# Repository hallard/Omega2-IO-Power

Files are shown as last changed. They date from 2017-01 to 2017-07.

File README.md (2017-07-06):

Power FTDI SPI and I2C or Full GPIO Shields for Onion Omega2
============================================================

These shields are used to power and to expose [Onion Omega2](https://onion.io/) gpio pins. it has just few minimal features such as wiring and 3V3 regulator and exists in 2 versions

- **Basic**: same size than Omega2, exposing Serial/SPI/I2C 
- **Full**: little bigger but exposing all Omega2 pins

Omega2 

**Features**   

- I2C Pullups placement
- I2C 4 pins connector
- SPI 6 pins connector
- Full Omega2 GPIO pins (Full version only)
- FTDI connector to Omega2 Serial0 (SMD or PTH) 
- USB Mini connector to power the whole thing and Omega2

You can find more information on Omega2 on their [site](https://onion.io/), it's really well [documented](https://docs.onion.io/omega2-docs/index.html) here.

**Waiting for V1.0 Boards from [PCBs.io](https://PCBs.io). I did not fully tested them yet, I will update ASAP. Use at your own risks**

Detailed Description
====================

Very simple, you plug your Omega2 on the shield, then you're ready to go. But pay attention, this board run at 3.3V.

You have 2 options to power board :

- Mini USB connector 5V goes to 3V3 regulator and you're ready to go
- Close JP1 and use **Only 3V3** FTDI connector that already have regulator on board. FTDI connector will then power the shield and Omega2 without any Mini USB plugged.

Take care if you are powered with mini USB and you want to use FTDI cable to connect to console, use a 3V3 FTDI cable and do not close JP1 connector

Here are example of FTDI 3V3 connector that should work 

- SparkFun Beefy 3 [FTDI Basic Breakout](https://www.sparkfun.com/products/13746) up to 600mA out at 3V3
- RocketScream [USB/Serial with CH340](http://www.rocketscream.com/blog/product/ch340g-usb-serial-adapter/) up to 100mA out at 3V3
- EZSBC [Usb To Serial UART 5V or 3V3](https://www.tindie.com/products/ddebeer/usb-to-serial--uart-5v-or-33v-695-/) up to 250mA out at 3V3
- WeMos [CH340G Breakout 5V 3.3V USB to serial](https://www.aliexpress.com/store/product/WEMOS-CH340G-Breakout-5V-3-3V-USB-to-serial-module/1331105_32664922086.html) up to 300mA out at 3V3

Schematics
==========

**Basic version** Click on image to zoom   
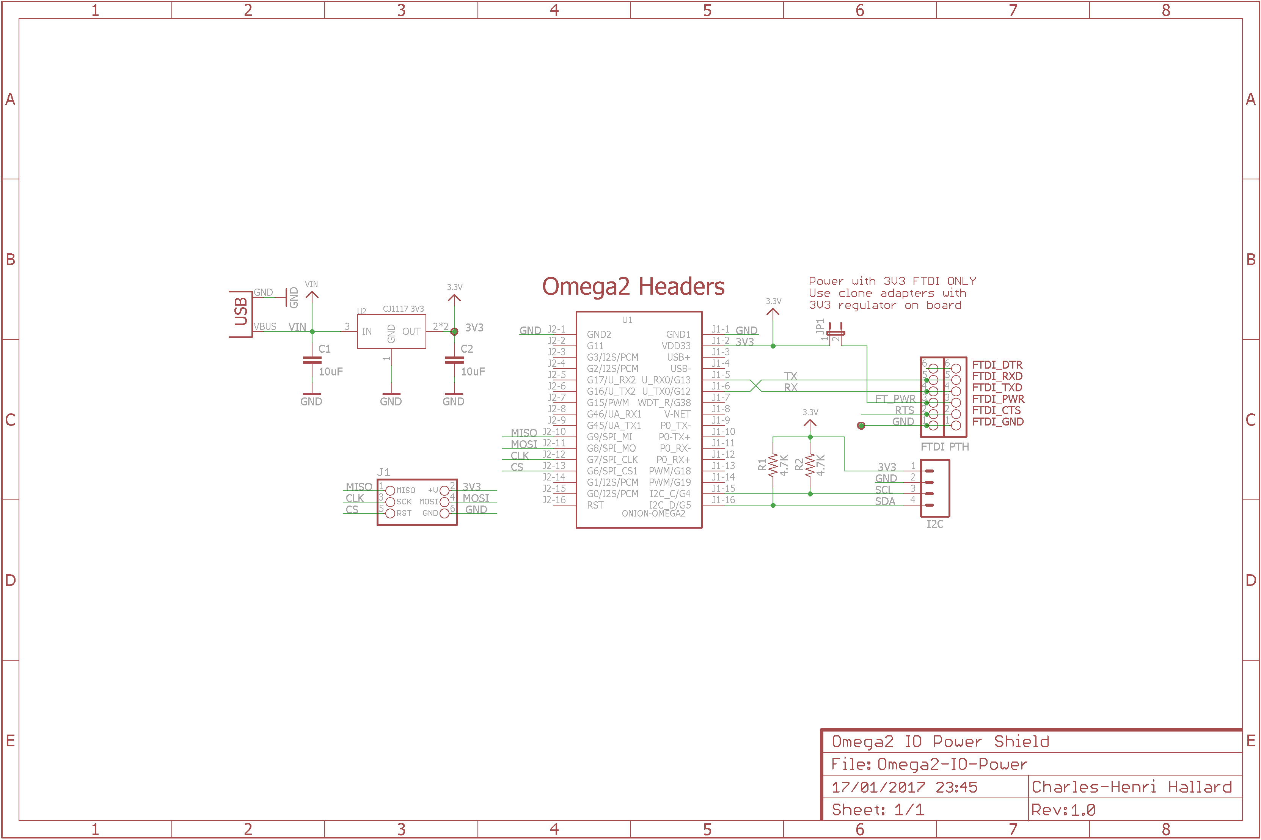
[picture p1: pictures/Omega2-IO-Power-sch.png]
  

**Full GPIO version** Click on image to zoom   
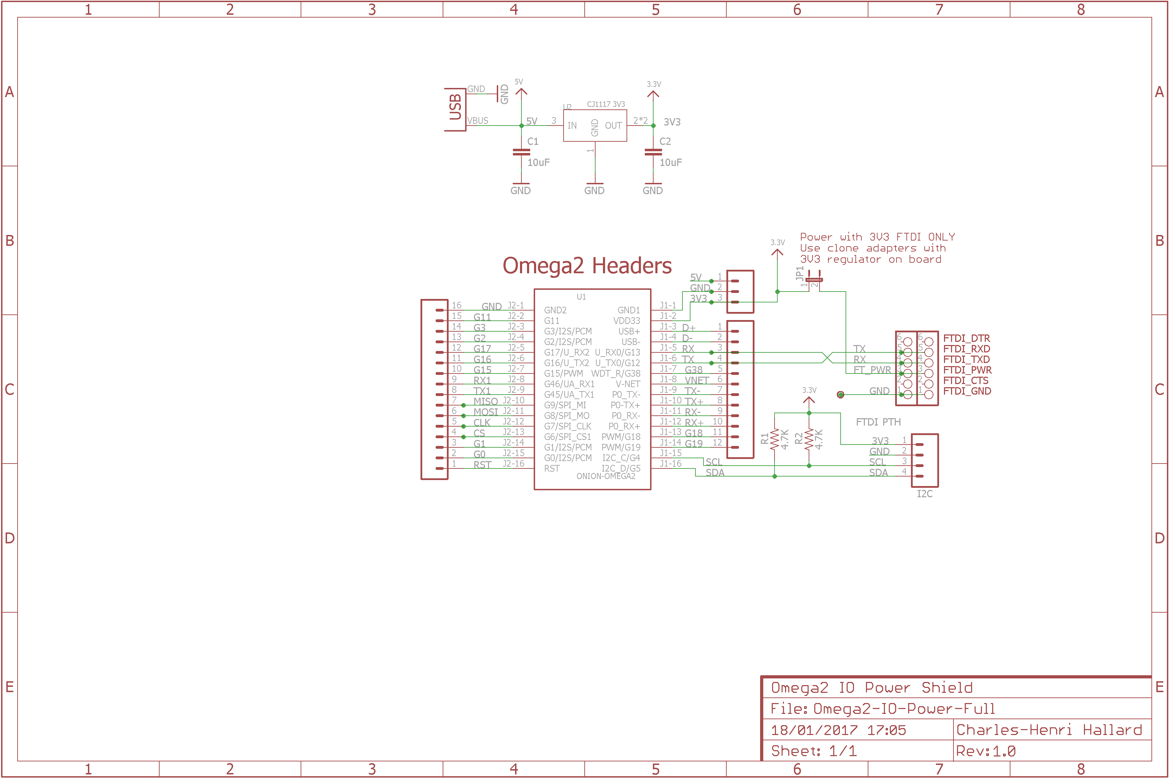
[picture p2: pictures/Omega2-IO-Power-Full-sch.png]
  

Boards
====== 

**Basic** Click on image to zoom   
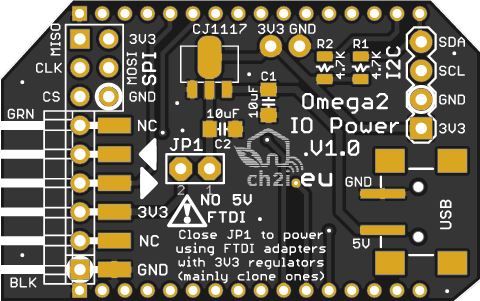
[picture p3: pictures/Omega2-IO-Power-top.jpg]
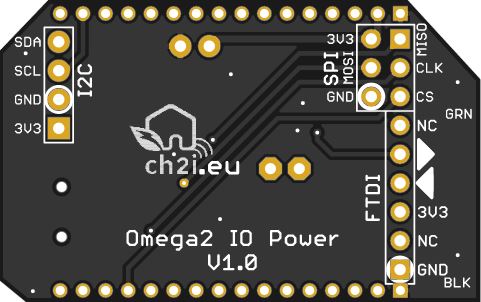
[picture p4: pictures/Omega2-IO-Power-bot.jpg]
&nbsp;&nbsp;&nbsp;

**Full GPIO version** Click on image to zoom   
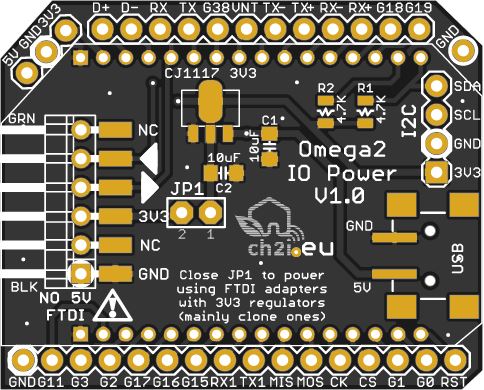
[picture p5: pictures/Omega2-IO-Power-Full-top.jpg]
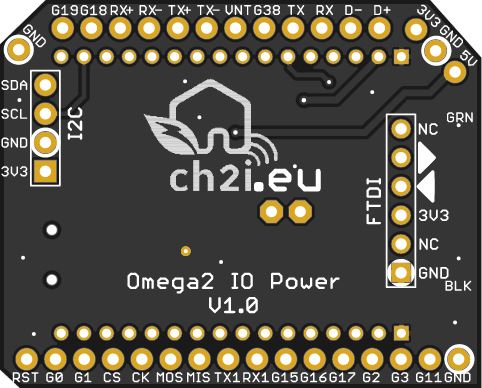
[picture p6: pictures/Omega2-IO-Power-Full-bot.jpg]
&nbsp;&nbsp;&nbsp;

You can order PCB of [Basic Version](https://PCBs.io/share/4976j) or [Full GPIO Version](https://PCBs.io/share/4KEo9) at PCBs.io. PCBs.io give me reward when you order my designed boards from their site. This is pretty good, because I can use these rewards to create and design new boards and order boards for a discounted price and share new boards. So if you don't care about PCB manufacturer please use PCBs.io.

Assembled boards (V1.0)
=======================

**Basic**
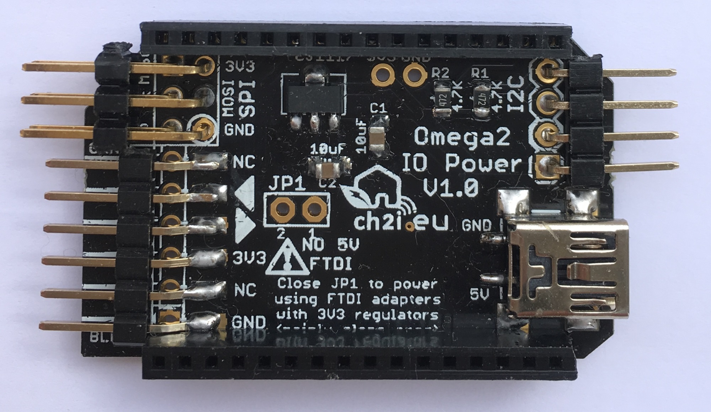
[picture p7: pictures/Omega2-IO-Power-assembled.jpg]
Basic


**Full GPIO version**  
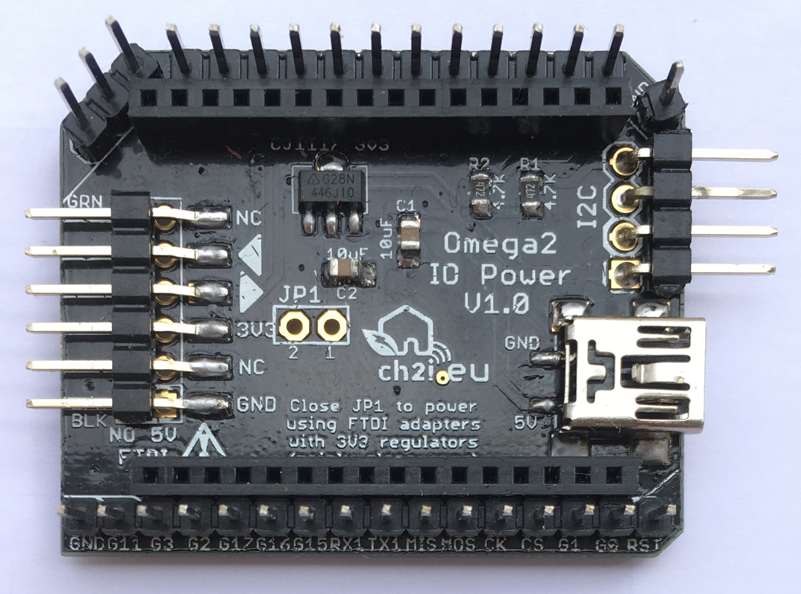
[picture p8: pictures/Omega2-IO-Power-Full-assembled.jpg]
Full


License
=======


This work is licensed under a Creative Commons Attribution-NonCommercial 4.0 International [License](http://creativecommons.org/licenses/by-nc/4.0)

If you want to do commercial stuff with this project, please contact [CH2i company](https://ch2i.eu) so we can organize an simple agreement.

Misc
====
See news and other projects on my [blog](https://hallard.me)

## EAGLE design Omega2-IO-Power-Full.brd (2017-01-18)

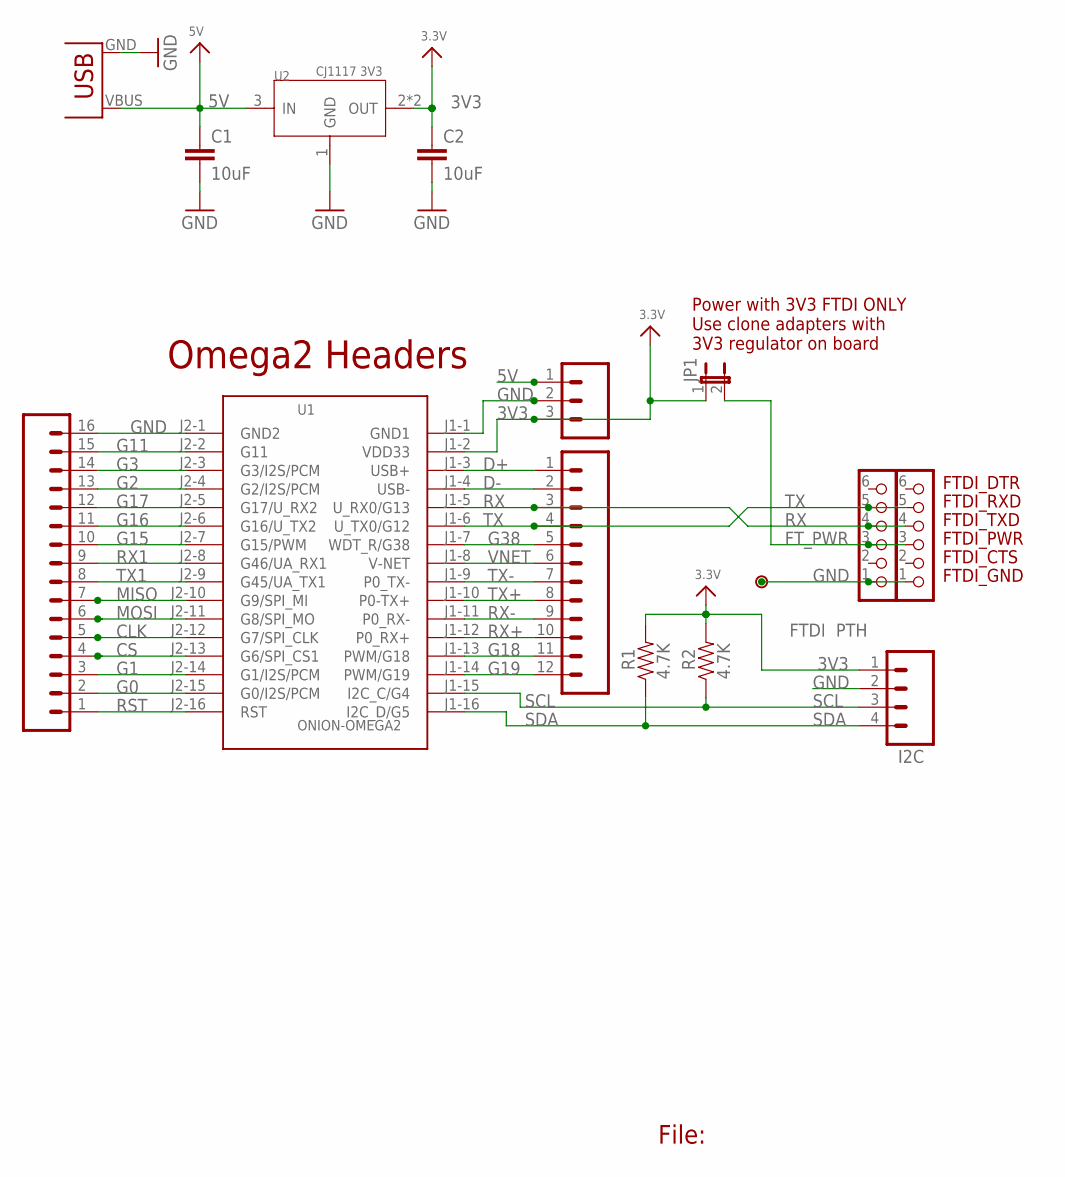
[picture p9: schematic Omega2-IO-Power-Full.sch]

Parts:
C1, C2: 10uF; 0805-CAP-LARGEPADS
FTDI: CON_HEADER_1X06-PTH; M1X6
I2C: M04PTH; 1X04
J1: M16PTH; 1X16
J2: M12PTH; 1X12
J7: M03PTH; 1X03
JP1: JUMPER2
P2: PADNORMAL; PAD
PTH: CON_HEADER_1X06; M1X6_MALE_RIGHT_ANGLED_SMD_NO_HOLES
R1, R2: 4.7K; 0805-RES
U1: ONION-OMEGA2; ONION-2MM-2X16
U2: CJ1117 3V3; SOT89
USB: USB_POWER; USB_MINIB_POWER

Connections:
3V3: C2.1, I2C.1, J7.3, JP1.1, R1.2, R2.2, U1.J1-2 (VDD33), U2.2 (OUT), U2.4 (OUT)
5V: C1.1, J7.1, U2.3 (IN), USB.VBUS (VCC)
CLK: J1.5, U1.J2-12 (G7/SPI_CLK)
CS: J1.4, U1.J2-13 (G6/SPI_CS1)
D+: J2.1, U1.J1-3 (USB+)
D-: J2.2, U1.J1-4 (USB-)
FT_PWR: FTDI.3, JP1.2, PTH.3
G0: J1.2, U1.J2-15 (G0/I2S/PCM)
G1: J1.3, U1.J2-14 (G1/I2S/PCM)
G2: J1.13, U1.J2-4 (G2/I2S/PCM)
G3: J1.14, U1.J2-3 (G3/I2S/PCM)
G11: J1.15, U1.J2-2 (G11)
G15: J1.10, U1.J2-7 (G15/PWM)
G16: J1.11, U1.J2-6 (G16/U_TX2)
G17: J1.12, U1.J2-5 (G17/U_RX2)
G18: J2.11, U1.J1-13 (PWM/G18)
G19: J2.12, U1.J1-14 (PWM/G19)
G38: J2.5, U1.J1-7 (WDT_R/G38)
GND: C1.2, C2.2, FTDI.1, I2C.2, J1.16, J7.2, P2.1, PTH.1, U1.J1-1 (GND1), U1.J2-1 (GND2), U2.1 (GND), USB.GND
MISO: J1.7, U1.J2-10 (G9/SPI_MI)
MOSI: J1.6, U1.J2-11 (G8/SPI_MO)
RST: J1.1, U1.J2-16 (RST)
RX: FTDI.4, J2.3, PTH.4, U1.J1-5 (U_RX0/G13)
RX1: J1.9, U1.J2-8 (G46/UA_RX1)
RX+: J2.10, U1.J1-12 (P0_RX+)
RX-: J2.9, U1.J1-11 (P0_RX-)
SCL: I2C.3, R2.1, U1.J1-15 (I2C_C/G4)
SDA: I2C.4, R1.1, U1.J1-16 (I2C_D/G5)
TX: FTDI.5, J2.4, PTH.5, U1.J1-6 (U_TX0/G12)
TX1: J1.8, U1.J2-9 (G45/UA_TX1)
TX+: J2.8, U1.J1-10 (P0-TX+)
TX-: J2.7, U1.J1-9 (P0_TX-)
VNET: J2.6, U1.J1-8 (V-NET)

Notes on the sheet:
File:
Omega2 Headers
FTDI_RXD
FTDI_TXD
FTDI_CTS
FTDI_DTR
FTDI_PWR
FTDI_GND
Power with 3V3 FTDI ONLY Use clone adapters with 3V3 regulator on board

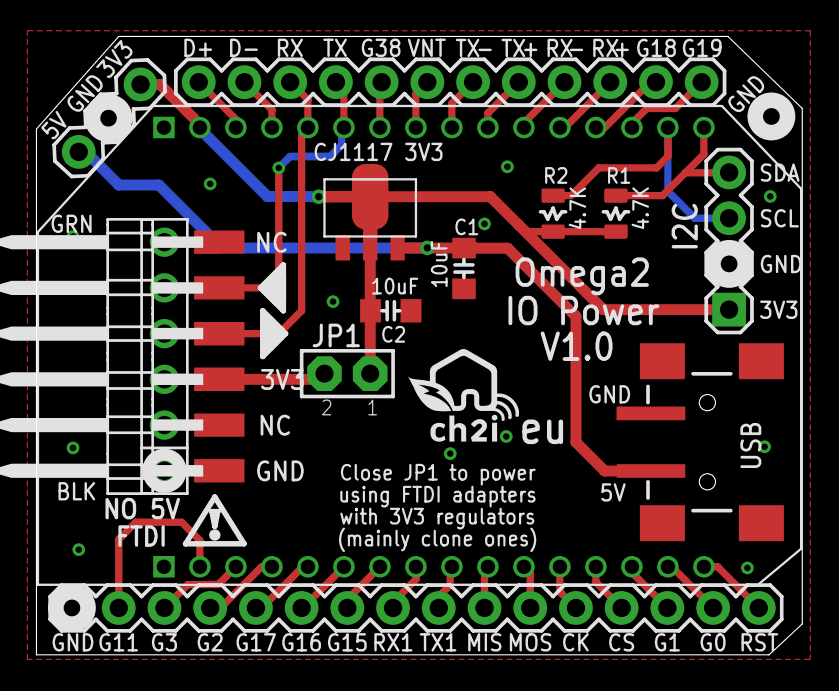
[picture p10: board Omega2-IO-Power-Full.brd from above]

Board: 2 copper layers, 42.5 x 34.4 mm, 17 parts (1 on the bottom side), 33 nets.

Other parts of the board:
U$2: LOGO_C2I_015
U$3: LOGO_CH2I_110MM

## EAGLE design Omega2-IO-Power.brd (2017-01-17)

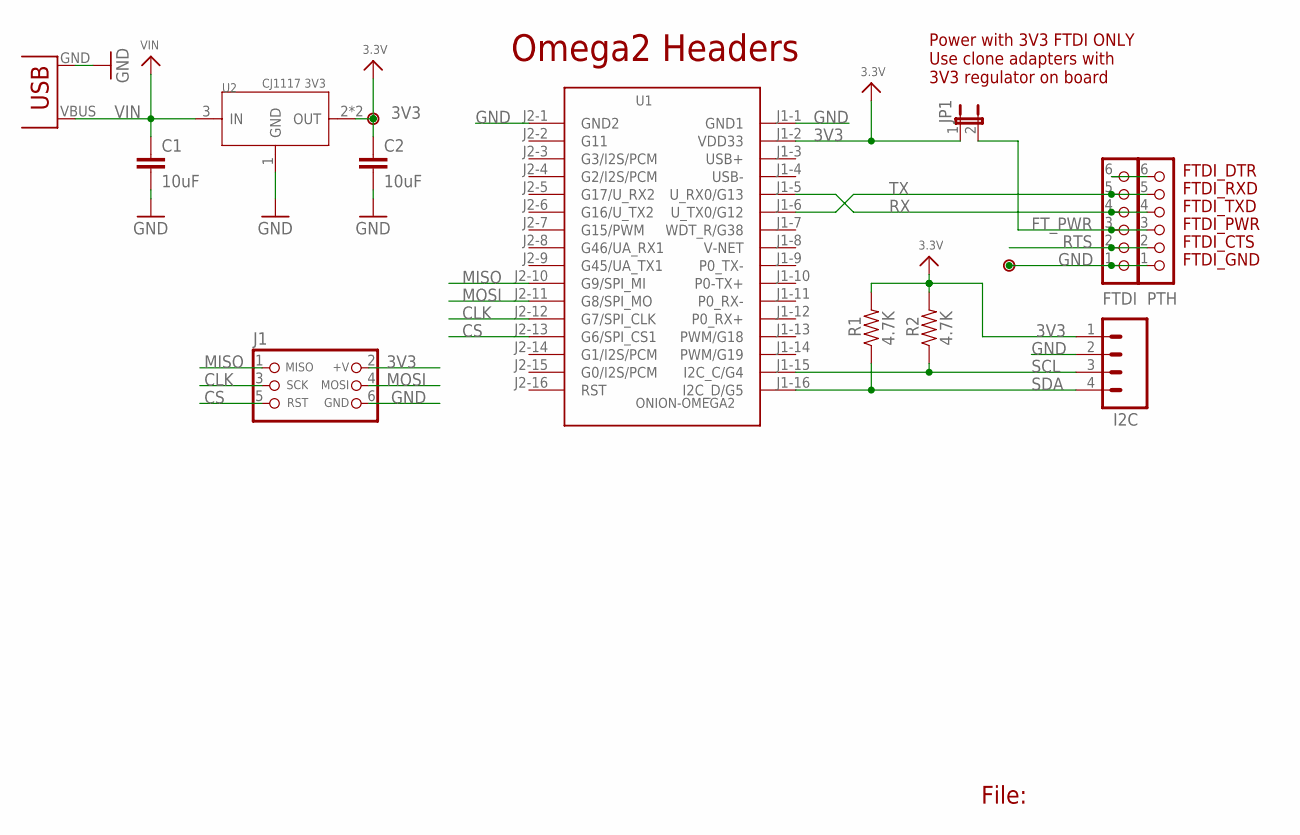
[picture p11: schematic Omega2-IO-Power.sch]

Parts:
C1, C2: 10uF; 0805-CAP-LARGEPADS
FTDI: CON_HEADER_1X06-PTH; M1X6
I2C: M04PTH; 1X04
J1: CON_HEADER_PRG_AVR_ICSP-PTH; HEADER_PRG_2X03
JP1: JUMPER2
P1, P2: PADNORMAL; PAD
PTH: CON_HEADER_1X06; M1X6_MALE_RIGHT_ANGLED_SMD_NO_HOLES
R1, R2: 4.7K; 0805-RES
U1: ONION-OMEGA2; ONION-2MM-2X16
U2: CJ1117 3V3; SOT89
USB: USB_POWER; USB_MINIB_POWER

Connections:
3V3: C2.1, I2C.1, J1.2 (+V), JP1.1, P1.1, R1.2, R2.2, U1.J1-2 (VDD33), U2.2 (OUT), U2.4 (OUT)
CLK: J1.3 (SCK), U1.J2-12 (G7/SPI_CLK)
CS: J1.5 (RST), U1.J2-13 (G6/SPI_CS1)
FT_PWR: FTDI.3, JP1.2, PTH.3
GND: C1.2, C2.2, FTDI.1, I2C.2, J1.6 (GND), P2.1, PTH.1, U1.J1-1 (GND1), U1.J2-1 (GND2), U2.1 (GND), USB.GND
MISO: J1.1 (MISO), U1.J2-10 (G9/SPI_MI)
MOSI: J1.4 (MOSI), U1.J2-11 (G8/SPI_MO)
RST: FTDI.6, PTH.6
RTS: FTDI.2, PTH.2
RX: FTDI.4, PTH.4, U1.J1-5 (U_RX0/G13)
SCL: I2C.3, R2.1, U1.J1-15 (I2C_C/G4)
SDA: I2C.4, R1.1, U1.J1-16 (I2C_D/G5)
TX: FTDI.5, PTH.5, U1.J1-6 (U_TX0/G12)
VIN: C1.1, U2.3 (IN), USB.VBUS (VCC)

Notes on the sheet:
File:
Omega2 Headers
FTDI_RXD
FTDI_TXD
FTDI_CTS
FTDI_DTR
FTDI_PWR
FTDI_GND
Power with 3V3 FTDI ONLY Use clone adapters with 3V3 regulator on board

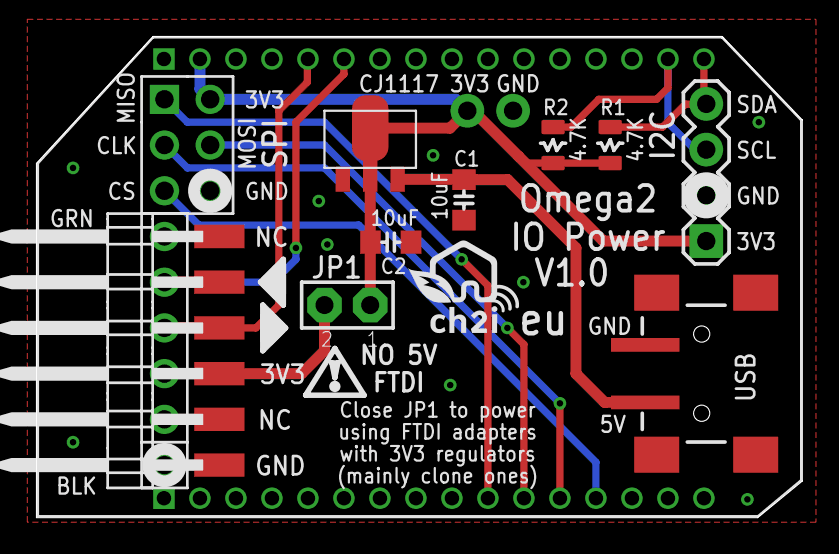
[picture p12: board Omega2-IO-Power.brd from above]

Board: 2 copper layers, 42.5 x 26.7 mm, 16 parts (1 on the bottom side), 14 nets.

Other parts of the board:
U$2: LOGO_C2I_015
U$4: LOGO_CH2I_75MM

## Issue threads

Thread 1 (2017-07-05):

CJ1117

dwhacks, 2017-07-05:
I noticed there is no BOM, yet all the parts are labeled on the board. Package sizes are still unknown, and I also have never seen a CJ1117. What is the package size? And is this regulator similar to the other 1117 variants.

I received my v1.0 boards yesterday, lets hope they are all good!

kasmasiini, 2017-07-05:
I have the same question about the BOM. I believe the regulator is similar to other 1117 and it looks like a SOT89 package. I would have hoped it was SOT223 as I have LD1117S33C in my inventory, but it's too large. The resistor seems to be 0805 and the cap 1206 package.

kasmasiini, 2017-07-05:
This LDO regulator might fit and the terminal pinout is compatible: [AZ1117CR-33TRG1](http://eu.mouser.com/ProductDetail/Diodes-Incorporated/AZ1117CR-33TRG1/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)

It would still be interesting to hear from @hallard about the official BOM.

hallard, 2017-07-06:
Sorry guys,
The regulator reference is AZ1117CR-3.3TRG1, it's like an AMS1117 in smaller footprint
You can find it at

- [mouser](http://www2.mouser.com/Search/ProductDetail.aspx?R=AZ1117CR-3.3TRG1)
- [digikey](https://www.digikey.com/products/en?keywords=AZ1117CR-3.3TRG1)

Components are 0805 package for hand soldering if needed and USB connector is coming from various Ebay sellers. I've removed the unused pins like this soldering only VCC and GND pin is easier ;-)

Closed 2017-07-06.

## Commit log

2017-01-17 Added PCBs.io Link
2017-07-06 Added Assembled Pictures

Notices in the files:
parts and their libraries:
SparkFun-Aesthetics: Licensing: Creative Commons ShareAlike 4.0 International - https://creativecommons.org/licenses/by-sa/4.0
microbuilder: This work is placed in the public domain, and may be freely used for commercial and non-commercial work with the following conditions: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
